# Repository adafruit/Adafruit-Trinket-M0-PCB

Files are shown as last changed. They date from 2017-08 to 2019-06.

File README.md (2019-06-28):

## Adafruit Trinket M0 PCB

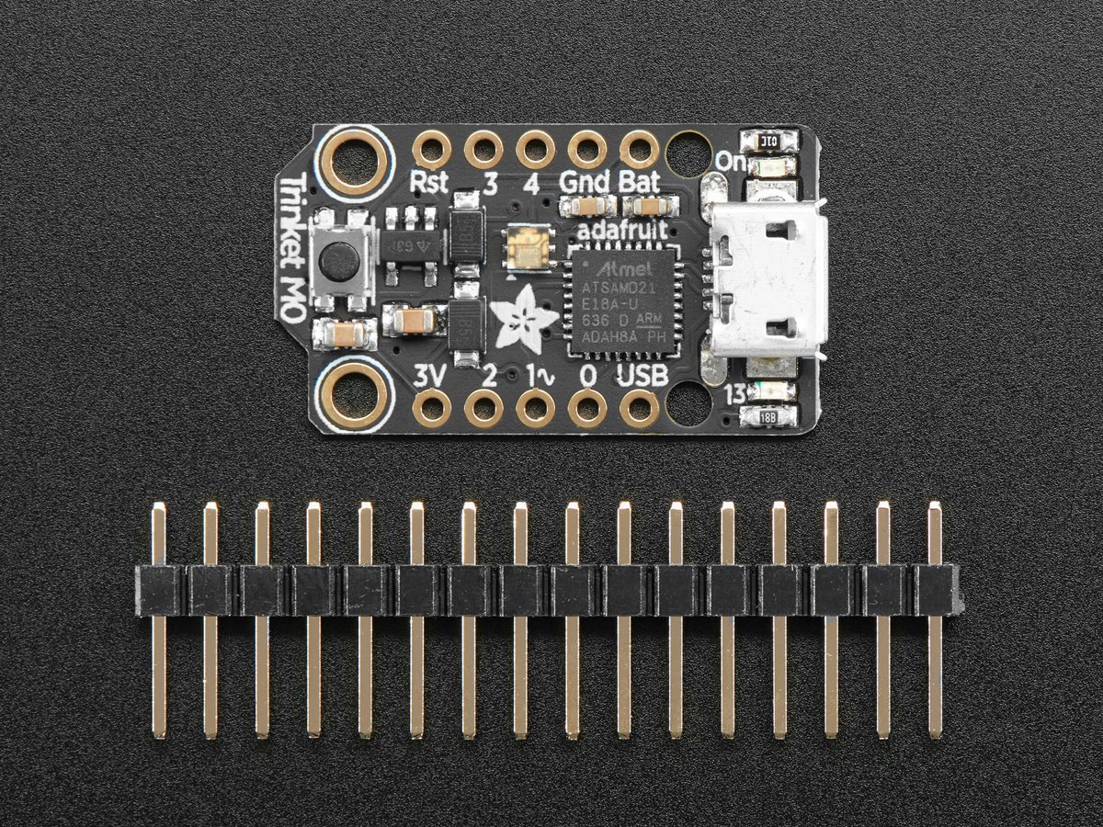
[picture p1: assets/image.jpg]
<a href="http://www.adafruit.com/products/3500"><br/>
Click here to purchase one from the Adafruit shop</a>

This is the CAD & PCB data for the Adafruit Trinket M0. PCB format is EagleCAD schematic and board layout

For more details, check out the product page at
* https://www.adafruit.com/products/3500

### Description

The Adafruit Trinket M0 may be small, but do not be fooled by its size! It's a tiny microcontroller board, built around the Atmel ATSAMD21, a little chip with a lot of power. We wanted to design a microcontroller board that was small enough to fit into any project, and low cost enough to use without hesitation. Perfect for when you don't want to give up your expensive dev-board and you aren't willing to take apart the project you worked so hard to design. It's our lowest-cost CircuitPython programmable board!

We've taken the same form factor we used for the original ATtiny85-based Trinket and gave it an upgrade. The Trinket M0 has swapped out the lightweight ATtiny85 for a ATSAMD21E18 powerhouse. It's just as small, and it's easier to use, so you can do more.

The most exciting part of the Trinket M0 is that while you can use it with the Arduino IDE, we are shipping it with CircuitPython on board. When you plug it in, it will show up as a very small disk drive with main.py on it. Edit main.py with your favorite text editor to build your project using Python, the most popular programming language. No installs, IDE or compiler needed, so you can use it on any computer, even ChromeBooks or computers you can't install software on. When you're done, unplug the Trinket M0 and your code will go with you. Please check out the Trinket M0 CircuitPython guide for a list of capabilities and quick-start code examples - CircuitPython is easier to code but not as low-level and complete as Arduino.

### License

Adafruit invests time and resources providing this open source design, please support Adafruit and open-source hardware by purchasing products from [Adafruit](https://www.adafruit.com)!

Designed by Limor Fried/Ladyada for Adafruit Industries.

Creative Commons Attribution/Share-Alike, all text above must be included in any redistribution. See license.txt for additional details.

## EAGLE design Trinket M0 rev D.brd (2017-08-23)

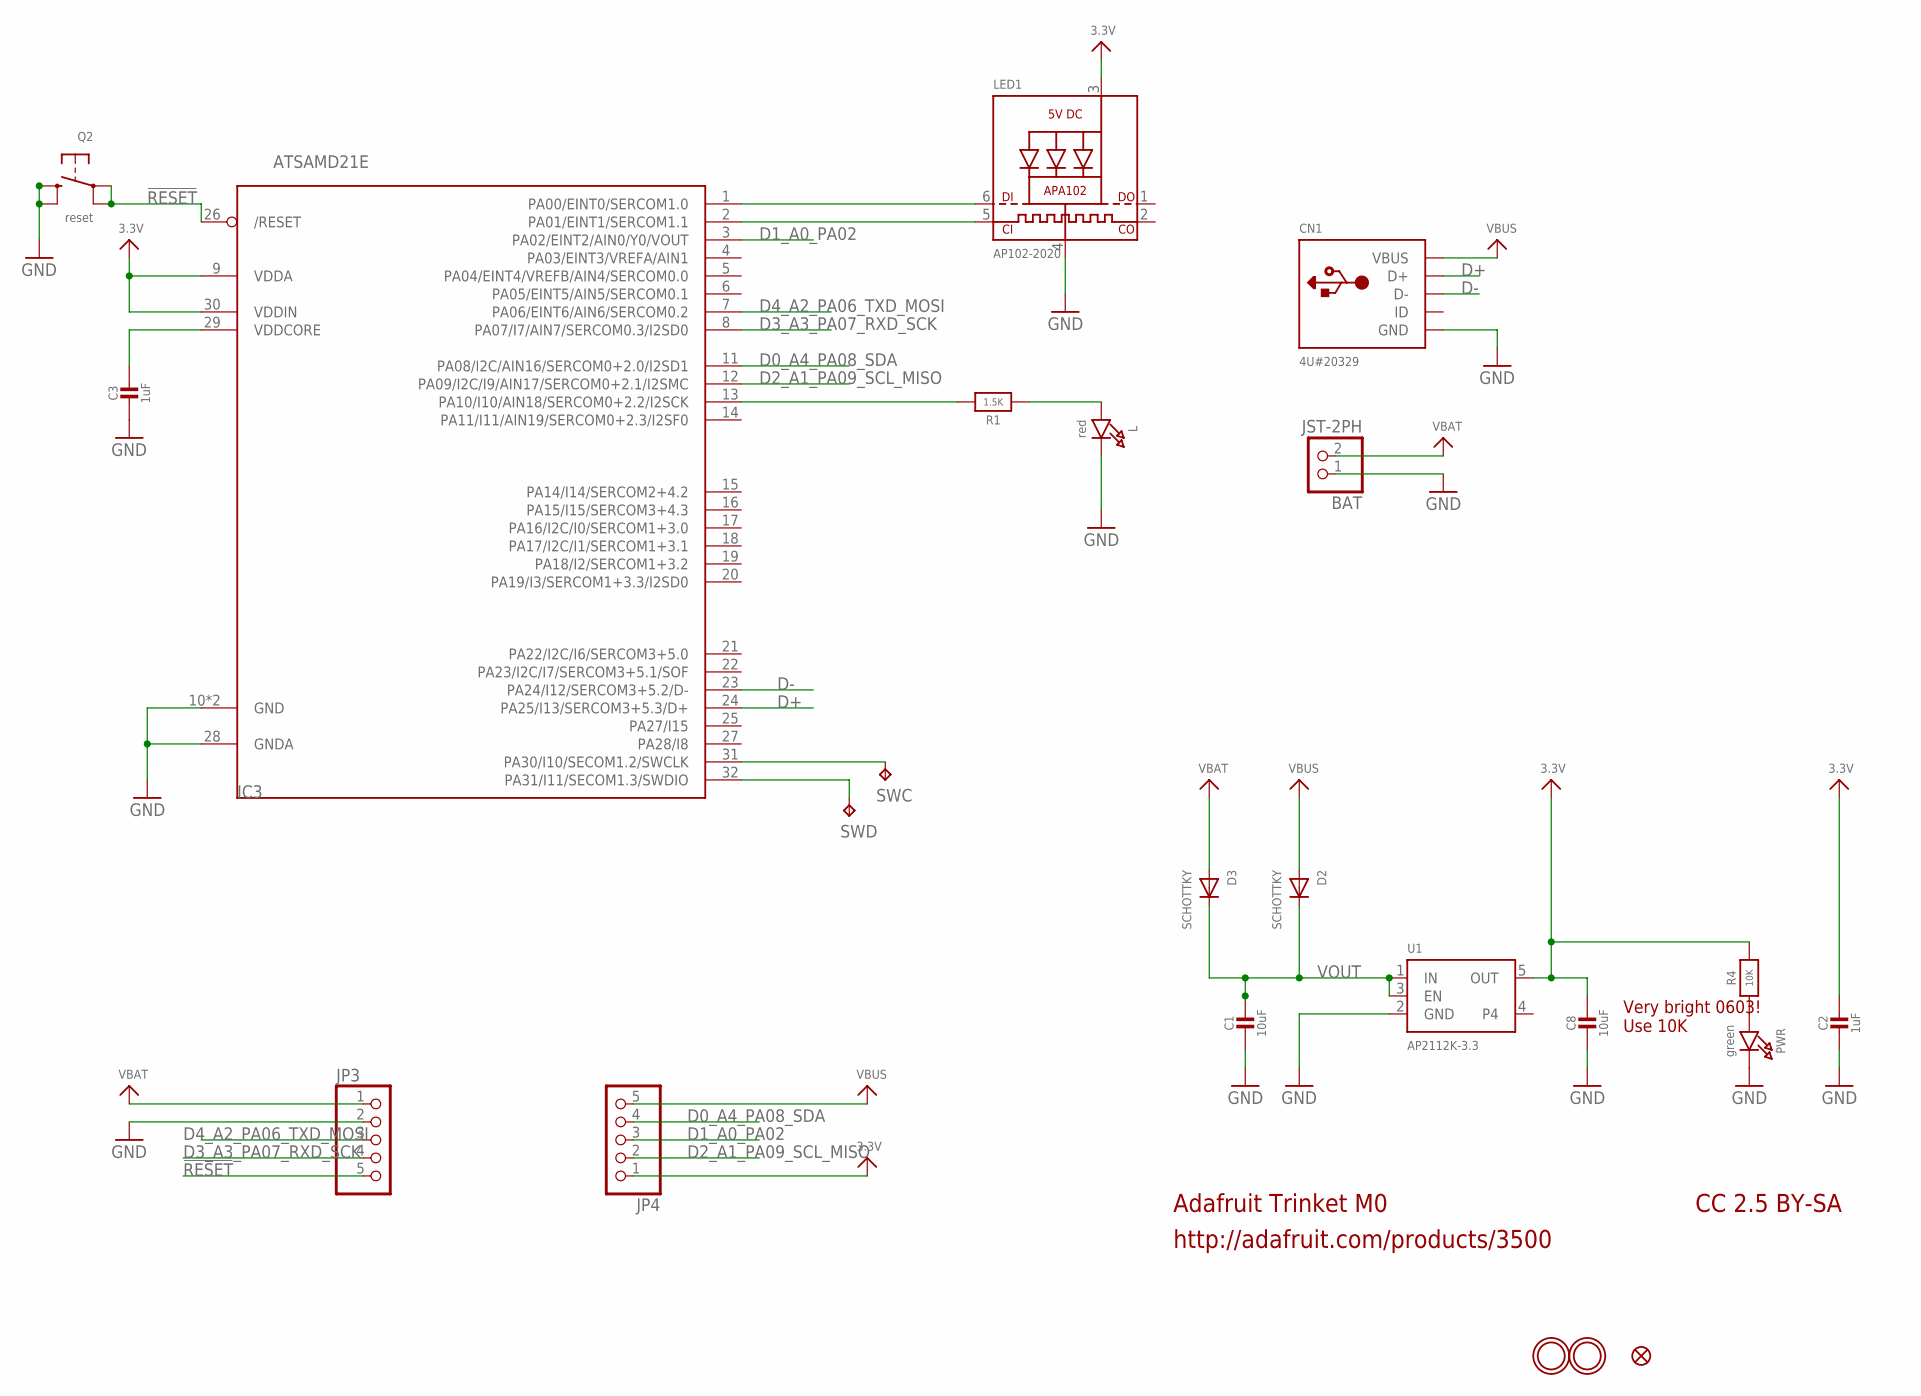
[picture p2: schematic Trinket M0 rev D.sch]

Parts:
BAT: JST-2PH; JSTPH2
C1, C8: 10uF; 0805-NO
C2, C3: 1uF; 0603-NO
CN1: 4U#20329; 4UCONN_20329_V2
D2, D3: SCHOTTKY; SOD-123FL
IC3: ATSAMD21E; QFN32_5MM
JP3, JP4: HEADER-1X576MIL; 1X05_ROUND_76
L: red; CHIPLED_0603_NOOUTLINE
LED1: AP102-2020; APA102_2020
PWR: green; CHIPLED_0603_NOOUTLINE
Q2: reset; BTN_KMR2_4.6X2.8
R1: 1.5K; 0603-NO
R4: 10K; 0603-NO
SWC: TPB1,27; B1,27
SWD: TPB1,27; B1,27
U1: AP2112K-3.3; SOT23-5
U$6: FIDUCIAL_1MM
U$8, U$9: MOUNTINGHOLE2.0; MOUNTINGHOLE_2.0_PLATED

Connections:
3.3V: C2.1, C8.1, IC3.9 (VDDA), IC3.30 (VDDIN), JP4.1, LED1.3 (VDD), R4.2, U1.5 (OUT)
!RESET: IC3.26 (/RESET), JP3.5, Q2.A, Q2.A' (P1)
A3: IC3.1 (PA00/EINT0/SERCOM1.0), LED1.6 (DI)
D0_A4_PA08_SDA: IC3.11 (PA08/I2C/AIN16/SERCOM0+2.0/I2SD1), JP4.4
D1_A0_PA02: IC3.3 (PA02/EINT2/AIN0/Y0/VOUT), JP4.3
D2_A1_PA09_SCL_MISO: IC3.12 (PA09/I2C/I9/AIN17/SERCOM0+2.1/I2SMC), JP4.2
D3_A3_PA07_RXD_SCK: IC3.8 (PA07/I7/AIN7/SERCOM0.3/I2SD0), JP3.4
D4_A2_PA06_TXD_MOSI: IC3.7 (PA06/EINT6/AIN6/SERCOM0.2), JP3.3
D+: CN1.D+, IC3.24 (PA25/I13/SERCOM3+5.3/D+)
D-: CN1.D-, IC3.23 (PA24/I12/SERCOM3+5.2/D-)
GND: BAT.1, C1.2, C2.2, C3.2, C8.2, CN1.BASE@1 (GND), CN1.BASE@2 (GND), CN1.GND, CN1.SPRT@1 (GND), CN1.SPRT@2 (GND), CN1.SPRT@3 (GND), CN1.SPRT@4 (GND), IC3.10 (GND), IC3.28 (GNDA), IC3.33 (GND), JP3.2, L.C, LED1.4 (GND), PWR.C, Q2.B (S), Q2.B' (S1), U1.2 (GND)
unnamed: L.A, R1.1
unnamed: IC3.13 (PA10/I10/AIN18/SERCOM0+2.2/I2SCK), R1.2
unnamed: IC3.31 (PA30/I10/SECOM1.2/SWCLK), SWC.TP
unnamed: IC3.32 (PA31/I11/SECOM1.3/SWDIO), SWD.TP
unnamed: PWR.A, R4.1
unnamed: IC3.2 (PA01/EINT1/SERCOM1.1), LED1.5 (CKI)
VBAT: BAT.2, D3.A, JP3.1
VBUS: CN1.VBUS, D2.A, JP4.5
VDDCORE: C3.1, IC3.29 (VDDCORE)
VOUT: C1.1, D2.C, D3.C, U1.1 (IN), U1.3 (EN)

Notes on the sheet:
Adafruit Trinket M0
http://adafruit.com/products/3500
CC 2.5 BY-SA
Very bright 0603! Use 10K

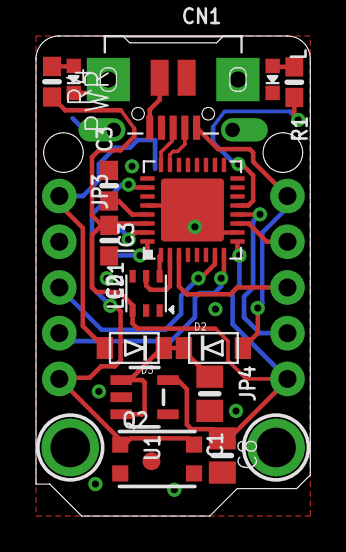
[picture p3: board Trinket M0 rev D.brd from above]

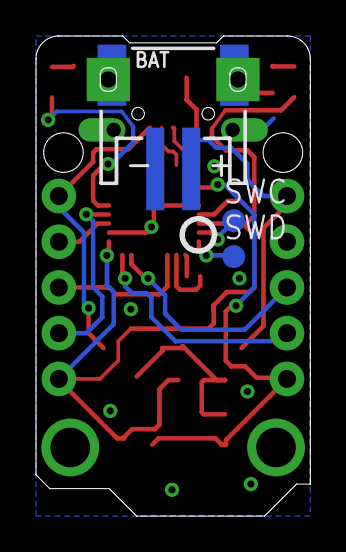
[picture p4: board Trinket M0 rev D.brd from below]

Board: 2 copper layers, 15.2 x 26.7 mm, 26 parts (5 on the bottom side), 21 nets.

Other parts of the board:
U$1: TRINKET_M0_BOTTOM
U$12: PCBFEAT-REV-040
U$20: TRINKET_M0_TOP

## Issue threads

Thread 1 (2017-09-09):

more Pins

pici, 2017-09-09:
I would love to have more output pins.
In my special case i wanna use SPI and I2C together.
What came in my mind when i look at  the great pcb design was: who needs these drill holes ?
Skip them and you have space for some extra (4) pins !
Would be great !

DirtyEngineer, 2017-09-13:
Check out the Tau by Rabid Prototypes.  It uses the ATSAMD21E17 chip which is just the smaller sibling (half the flash/ram) to the ATSAMD21E18 that is used in the Trinket M0. The advantage is that this board has all the pins broken out and is a very similar size to the Trinket footprint. The Tau is open source hardware so you can modify as needed.  http://rabidprototypes.com/product/tau/

ladyada, 2017-09-13:
thanks - im closing this because it's a suggestion not an issue :)

Closed 2017-09-13.

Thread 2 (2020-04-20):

Missing path to GND for LED 13 in board "rev D"

vgadoury, 2020-04-20:
Hi,
In "Trinket M0 rev D.brd", I can't see any trace connecting the GND pad of the LED 13 (compared to the power led for example). I'm quite new at Eagle, so maybe there's something I'm missing here. I tried displaying all the layers and that trace seems to be missing:
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

When compared to the board image from the website (https://learn.adafruit.com/assets/45722), where we can see the trace under the "13" (I can also see the bulge of this trace under the "13" on the Trinket M0 boards I have).

vgadoury, 2020-04-20:
Nevermind, I had to use the Ratsnet "X" button in Eagle to fill the power planes. Now it looks like the image on the website.

Closed 2020-04-20.

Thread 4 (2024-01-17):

Chip selection issue

DesmondZuo, 2024-01-17:
Hi! I'm trying to use the trinket m0 chip for my own project, and I ran into the following issue:

I detached the ATSAMD21E18A-U chip from the Trinket M0 and soldered onto my own board.
It can be detected by the arduino IDE program and write program into it, works correctly

However, I purchased the same chip from Digikey (ATSAMD21E18A-MUT), but has the same print of "ATSAMD21E18A-U" on the chip, it does not work. The Arduino IDE does not recognize this chip as an adafruit chip

There are variations on Digikey such as ATSAMD21E18A-AUT, I'm not sure which one I should use.
My goal is to use Arduino IDE and let it detect my purchased chip just like the adafruit detached ones.

Anyone have some ideas on that? Thanks a lot in advance!!

caternuson, 2024-01-18:
This guide covers the how, fwiw:
https://learn.adafruit.com/how-to-program-samd-bootloaders/overview

Closed 2024-01-18.

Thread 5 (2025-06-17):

SCL pad mislabeled in "Adafruit Trinket M0 pinout.pdf"

AlnisS, 2025-06-17:
PDF [Adafruit Trinket M0 pinout.pdf](https://github.com/adafruit/Adafruit-Trinket-M0-PCB/blob/master/Adafruit%20Trinket%20M0%20pinout.pdf) currently says

> I2C (SDA on pad 0, SCL on pad 1)

In fact, SCL is on pad 2 (pin 2).

I went on a bit of a wild goose chase before I found this page documenting that SCL is pin 2:
https://learn.adafruit.com/adafruit-trinket-m0-circuitpython-arduino/circuitpython-i2c#step-2985147

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

AlnisS, 2025-06-21:
Thank you, that is logical. I think I understand it now.

I also noticed that the pins are labeled with SDA/SCL on the back (but I didn't see because I put the trinket on a breadboard) 🤦

So, I guess the problem was on my end... but I wonder if there's some way to clarify this for others reading the pinout. Hmm.

Thank you for your patience!

Closed 2025-06-24.

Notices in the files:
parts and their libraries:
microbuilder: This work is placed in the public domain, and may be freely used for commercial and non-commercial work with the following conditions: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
